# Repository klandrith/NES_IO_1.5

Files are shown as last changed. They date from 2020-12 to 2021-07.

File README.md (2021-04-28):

NES-I/O 1.5
===========

From original Borti's project: https://github.com/borti4938/NES_IGR_for_NESRGB/tree/master/NES-IO

an idea by Arcade-TV from circuit-board.de :) Thank you very much!!!

The board replaces the silver box in NES frontloader. On this PCB the following components are included:

- AC input jack
- AC to DC conversion
- MultiAV (SNES and GC(*) are supported) 
- PIC16F684 microcontroller to control the NESRGB color palette and reset the console using your controller :D

All components you need are stated on the silkscreen. An complete overview as well as an English installation guide is coming soon ;)

Grab the firmware for the PIC16F684 here: https://github.com/borti4938/NES_IGR_for_NESRGB/tree/master/fw/IGR_for_NESRGB/
- current version: use the 'normal version' and flash the nesrgb_igr_684_var_led.hex
- oldest PCB version (with three 10k resistors next to the 74*125): use the 'risky version' and flash nesrgb_igr_684_risky_var_led.hex

(*) 3d-printed Helder/Buffalowing connector on assemblergames (http://assemblergames.com/l/threads/f-s-nes-top-loader-snes-style-multi-a-v-socket.50494/) also fits  
    thanks for figuring out, splits (shmups forum)

-- The Rev 1.5 add the audio module, and there is now a NO CUT version where a miniDIN 9pin and a miniDIN 4pin replace the SNES/GC Multiout.
--
-- YOU'LL NEED TO REMOVE THE 3 RESISTORS ON THE RGB LINES OF THE NESRGB BOARD IF YOU ARE USING THE NOCUT BOARDS
--

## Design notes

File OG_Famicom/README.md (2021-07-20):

Famicom-I/O 1.5
===========

This is the Original Famicom folder.

The Classic SNES Multiout requires the following PCBs (gerber zipped files):
- Famicom_IO_SNES_REV1.5
- Audio_Blank
- Famicon_IO_Jack_Spacer

The NOCUT requires the following PCBs (gerber zipped files):
- Famicom_IO_NOCUT_REV1.5
- Audio_Blank
- Famicon_IO_Jack_Spacer

Installation Notes:
- For the NOCUT version, you need to remove the 75omhs resistors on the RGB lines of the NESRGB

- PDF installation guide link: https://github.com/TRP-Retromods/NES_IO_1.5/blob/master/OG_Famicom/Famicom_IO_Installation.pdf

Audio
- For default installation, you have 3 possibilies

1) No expansion: you simply take CPU pins 1&2 to A&B inputs of the NESRGB, then link O ouput to "Mono" of the Famicom I/O
2) Expansion only: you need to CUT the trace going to pin 45 of the Cart slot (as per Tim's installation guide). As Tim said: "connect the A and B inputs to the PPU, connect the cartridge output pin via a resistor to the mixing point (located next to jumper J5). The cartridge input pin needs to be disconnected from the existing mixer circuit on the motherboard. Replace it with a mid supply reference (maybe 4k7 to +5V, 4k7 to ground, bypassed with a 10u capacitor)"
3) Original mixing (TO BE TESTED) : quote "Alternatively, you can continue to use the original mixer circuit and just use the NESRGB audio circuit as a buffer. To do this connect the cartridge output through a 27k resistor to the A audio input on the NESRGB board. Leave the B audio input unconnected. This makes the audio circuit into unity gain buffer. You will also probably want to remove C30 as it will attenuate the high frequency signals too much in this configuration."

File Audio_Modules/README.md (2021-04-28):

NES-I/O 1.5
===========

This is the Audio Module folder.

You'll find audio that can replace the blank one on the NES I/O / Famicom I/O Rev 1.5

* Tianfeng audio - This will take directly from the CPU Pin 1/2 and expansion cart pin.

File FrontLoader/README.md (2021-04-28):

NES-I/O 1.5
===========

This is the FrontLoader folder.

The Classic SNES Multiout requires the following PCBs (gerber zipped files):
- NES_IO_US_REV1.5_SNES
- Audio_Blank

The NOCUT requires the following PCBs (gerber zipped files):
- NES_IO_US_REV1.5_NOCUT
- miniDIN4_spacer
- Audio_Blank

-- You need to send to fab the blank audio module PCB for all versions, and the miniDIN 4 spacer IN 1MM THICK for the NOCUT.
--
-- You'll need to cut some parts on the PCBs: they are currently designed to avoid extra costs on castelated vias.
--
-- They are around the RCA plugs and on the miniDIN4_spacer.
--

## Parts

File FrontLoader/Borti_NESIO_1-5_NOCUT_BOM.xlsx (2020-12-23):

Manufacturer Part Number | Manufacturer | Digi-Key Part Number | Customer Reference | Reference Designator | Packaging | Part Status | Quantity | Unit Price | Extended Price | Quantity Available | Mfg Std Lead Time | Description | RoHS Status | Lead Free Status | REACH Status
RCJ-012 | CUI Devices | CP-1401-ND | BORTI'S NES IO |  | Bulk | Active | 1 | 1.03 | $1.03 | 35 | 11 Weeks | CONN RCA JACK MONO 3.2MM R/A | RoHS Compliant | Lead free | Not Available
RCJ-014 | CUI Devices | CP-1403-ND | BORTI'S NES IO |  | Bulk | Active | 1 | 1.03 | $1.03 | 2923 | 11 Weeks | CONN RCA JACK MONO 3.2MM R/A | RoHS Compliant | Lead free | Not Available
EEE-1VA100WR | Panasonic Electronic Components | PCE3948CT-ND | BORTI'S NES IO | C4 | Cut Tape (CT) | Active | 1 | 0.42 | $0.42 | 33434 | 26 Weeks | CAP ALUM 10UF 20% 35V SMD | RoHS Compliant | Lead free | Not Available
UWJ0J101MCL1GB | Nichicon | 493-9777-1-ND | BORTI'S NES IO | C5 | Cut Tape (CT) | Active | 1 | 0.48 | $0.48 | 3177 | 20 Weeks | CAP ALUM 100UF 20% 6.3V SMD | ROHS3 Compliant | Lead free | REACH Unaffected
OKI-78SR-5/1.5-W36-C | Murata Power Solutions Inc. | 811-2196-5-ND | BORTI'S NES IO |  | Tray | Active | 1 | 6.08 | $6.08 | 1295 | 14 Weeks | DC DC CONVERTER 5V 8W | RoHS Compliant | Lead free | REACH Unaffected
74LVX125MX | ON Semiconductor | 74LVX125MXCT-ND | BORTI'S NES IO |  | Cut Tape (CT) | Active | 1 | 0.83 | $0.83 | 1578 | 8 Weeks | IC BUF NON-INVERT 3.6V 14SOIC | ROHS3 Compliant | Lead free | REACH Unaffected
CL21B103KAANNNC | Samsung Electro-Mechanics | 1276-2434-1-ND | BORTI'S NES IO | C1, C3, C6 | Cut Tape (CT) | Active | 3 | 0.14 | $0.42 | 118307 | 22 Weeks | CAP CER 10000PF 25V X7R 0805 | ROHS3 Compliant | Lead free | REACH Unaffected
56000001009 | Littelfuse Inc. | WK6235-ND | BORTI'S NES IO | F1 | Bulk | Active | 1 | 1.19 | $1.19 | 21271 | 12 Weeks | FUSE HOLDER RADIAL 250V 6.3A PCB | ROHS3 Compliant | Lead free | Not Available
MRT 1.25-BULK | Bel Fuse Inc. | 507-1112-ND | BORTI'S NES IO | F1 | Bulk | Active | 1 | 0.48 | $0.48 | 914 | 18 Weeks | FUSE BRD MNT 1.25A 250VAC RADIAL | ROHS3 Compliant | Lead free | REACH Unaffected
PIC16F684-I/SL | Microchip Technology | PIC16F684-I/SL-ND | BORTI'S NES IO |  | Tube | Active | 1 | 2.06 | $2.06 | 3297 | 19 Weeks | IC MCU 8BIT 3.5KB FLASH 14SOIC | ROHS3 Compliant | Lead free | REACH Unaffected
1N5059GP-E3/54 | Vishay Semiconductor Diodes Division | 1N5059GP-E3/54GICT-ND | BORTI'S NES IO | D1, D2, D3, D4 | Cut Tape (CT) | Active | 4 | 0.52 | $2.08 | 19206 | 18 Weeks | DIODE GEN PURP 200V 1A DO204AC | ROHS3 Compliant | Lead free | REACH Unaffected
25PK2200MEFC12.5X20 | Rubycon | 1189-1731-ND | BORTI'S NES IO | C2 | Bulk | Active | 1 | 1.19 | $1.19 | 16646 | 17 Weeks | CAP ALUM 2200UF 20% 25V RADIAL | ROHS3 Compliant | Lead free | REACH Unaffected
CL21B104MBCNNNC | Samsung Electro-Mechanics | 1276-2450-1-ND | BORTI'S NES IO | C7, C9 | Cut Tape (CT) | Obsolete | 2 | 0.14 | $0.28 | 2069590 | 22 Weeks | CAP CER 0.1UF 50V X7R 0805 | ROHS3 Compliant | Lead free | REACH Unaffected
RMCF0805FT1K00 | Stackpole Electronics Inc | RMCF0805FT1K00CT-ND | BORTI'S NES IO | R6, R7 | Cut Tape (CT) | Active | 2 | 0.15 | $0.30 | 370416 | 18 Weeks | RES 1K OHM 1% 1/8W 0805 | ROHS3 Compliant | Lead free | REACH Unaffected
RMCF0805FT180R | Stackpole Electronics Inc | RMCF0805FT180RCT-ND | BORTI'S NES IO | R1, R2 | Cut Tape (CT) | Active | 2 | 0.15 | $0.30 | 37701 | 18 Weeks | RES 180 OHM 1% 1/8W 0805 | ROHS3 Compliant | Lead free | REACH Unaffected
PJ-002A | CUI Devices | CP-002A-ND | BORTI'S NES IO |  | Bulk | Active | 1 | 0.85 | $0.85 | 39799 | 11 Weeks | CONN PWR JACK 2X5.5MM SOLDER | RoHS Compliant | Lead free | Not Available
RMCF0805FT10K0 | Stackpole Electronics Inc | RMCF0805FT10K0CT-ND | BORTI'S NES IO | J2 | Cut Tape (CT) | Active | 1 | 0.15 | $0.15 | 4314324 | 18 Weeks | RES 10K OHM 1% 1/8W 0805 | ROHS3 Compliant | Lead free | REACH Unaffected
MDJ-009-FS | Adam Tech | 2057-MDJ-009-FS-ND |  |  | Tray | Active | 1 | 1.73 | $1.73 | 758 | 9 Weeks | CONN JACK FMALE MINI DIN 9P SLDR | ROHS3 Compliant | Lead free | REACH Unaffected
KMDGX-4S-BS | Kycon, Inc. | 2092-KMDGX-4S-BS-ND |  |  | Tray | Active | 1 | 1.8 | $1.80 | 6594 | 20 Weeks | CONN RCPT FMALE MINI DIN 4P SLDR | RoHS Compliant | Lead free | Not Available
310-87-108-41-001101 | Preci-Dip | 1212-1097-ND |  |  | Bulk | Active | 1 | 0.78 | $0.78 | 5099 | 10 Weeks | CONN SOCKET 8POS 0.1 GOLD PCB | ROHS3 Compliant | Lead free | REACH Unaffected
TS-108-T-A | Samtec Inc. | SAM1112-08-ND |  |  | Bulk | Active | 1 | 1.49 | $1.49 | 1752 | 2 Weeks | CONN HEADER VERT 8POS 2.54MM | ROHS3 Compliant | Lead free | REACH Unaffected

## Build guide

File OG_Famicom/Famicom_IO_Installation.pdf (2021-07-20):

FAMICOM I/O Installation Guide | 1

# Installation of the FAMICOM I/O (Classic and No Cut)

# FIRST YOU NEED TO READ THE ORIGINAL INSTALLATION OF THE NESRGB FROM TIM WORTHINGTON AND NES I/O FROM BORTI (yes the Front Loader one) TO UNDERSTAND WHAT YOU ARE DOING Links:

# https://etim.net.au/nesrgb/installation-famicom/ https://github.com/borti4938/NES_IGR_for_NESRGB/blob/master/NES-IO/NESIO_Installation.pdf

# THIS IS EXPERIMENTAL, I CANNOT BE HOLD RESPONSIBLE FOR ANY DAMAGE CAUSED TO YOUR CONSOLE

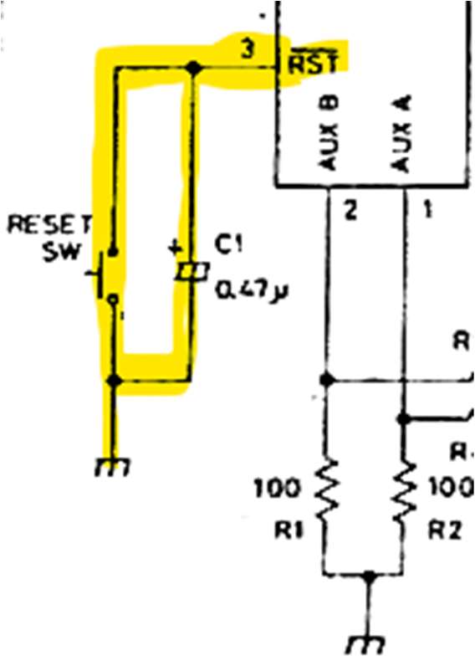
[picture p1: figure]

FAMICOM I/O Installation Guide | 2

### 1) RGB/Video/Palette

Those are identical as a classic NESRGB+NES I/O installation. Check respective installation guides of each.

### 2) RESET

a) Preparations
The reset is different in the OG Famicom from the NES Front Loader: there’s no CIC and you cannot intercept the reset signal which is going straight to the CPU pin:

You need to intercept the signal and re-route the Famicom I/O BEFORE it goes the CPU. You can cut the trace close the reset switch:

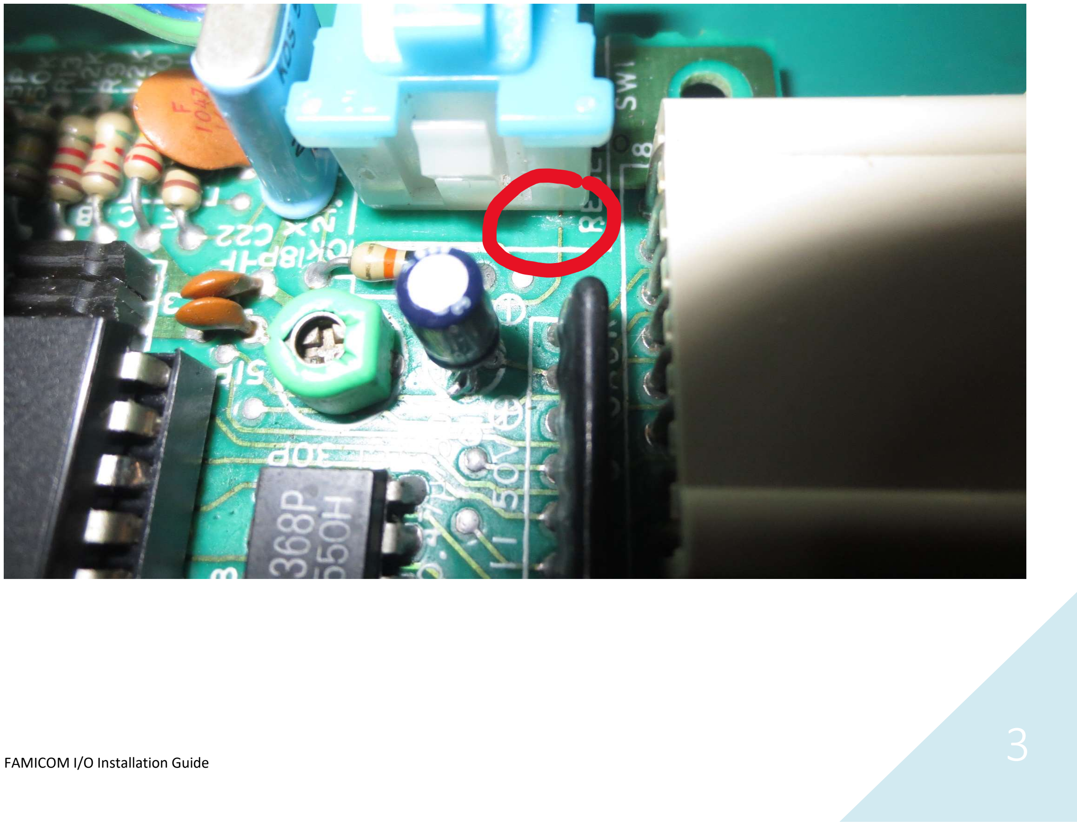
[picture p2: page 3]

FAMICOM I/O Installation Guide

3

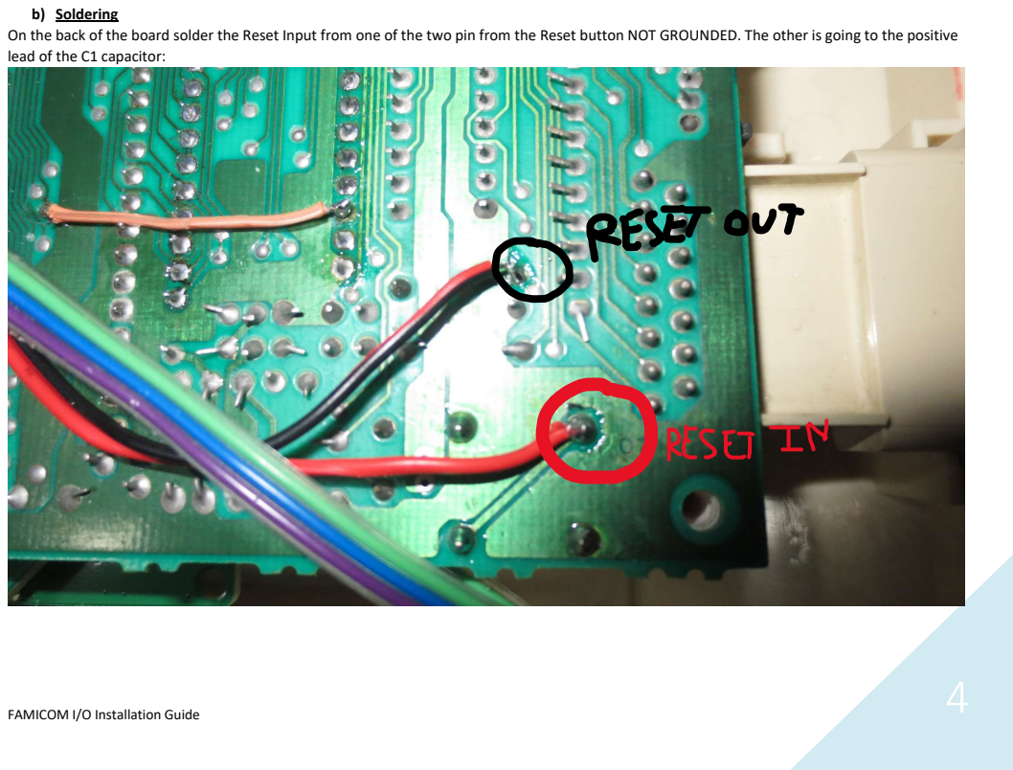
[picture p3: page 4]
FAMICOM I/O Installation Guide

b) Soldering
On the back of the board solder the Reset Input from one of the two pin from the Reset button NOT GROUNDED. The other is going to the positive
lead of the C1 capacitor:

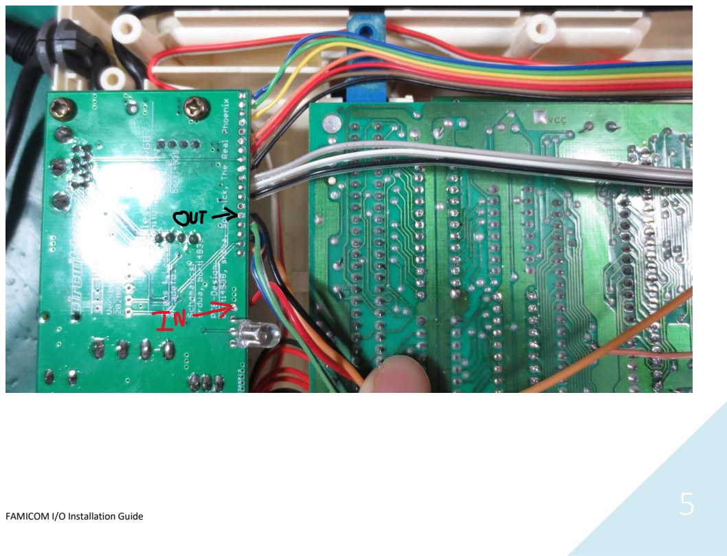
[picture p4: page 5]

FAMICOM I/O Installation Guide

### 3) PULSE, LATCH and DATA

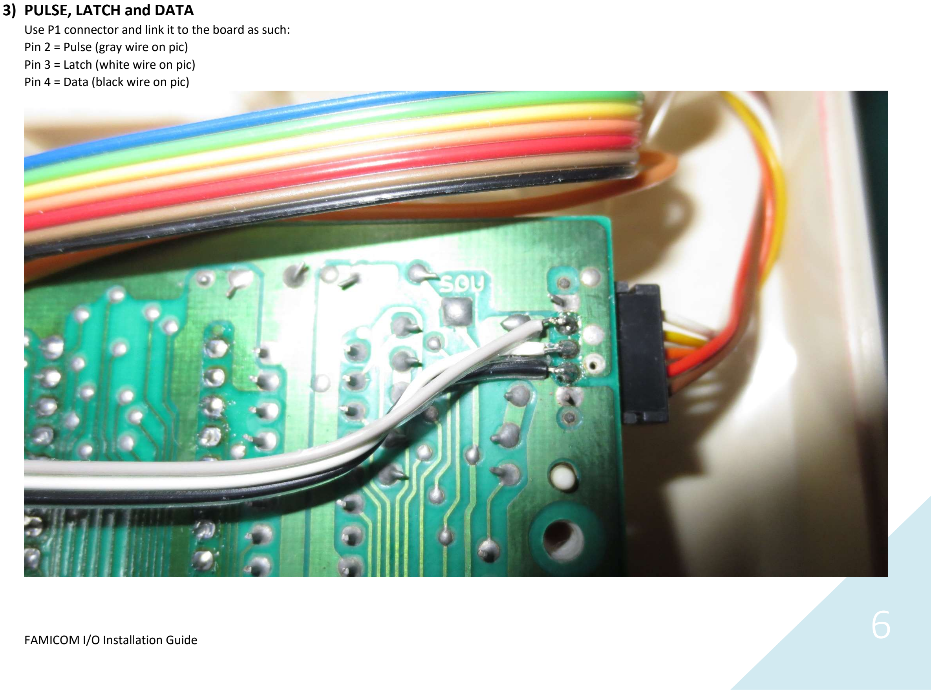
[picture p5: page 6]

FAMICOM I/O Installation Guide | 6

Use P1 connector and link it to the board as such: Pin 2 = Pulse (gray wire on pic)
Pin 3 = Latch (white wire on pic)
Pin 4 = Data (black wire on pic)

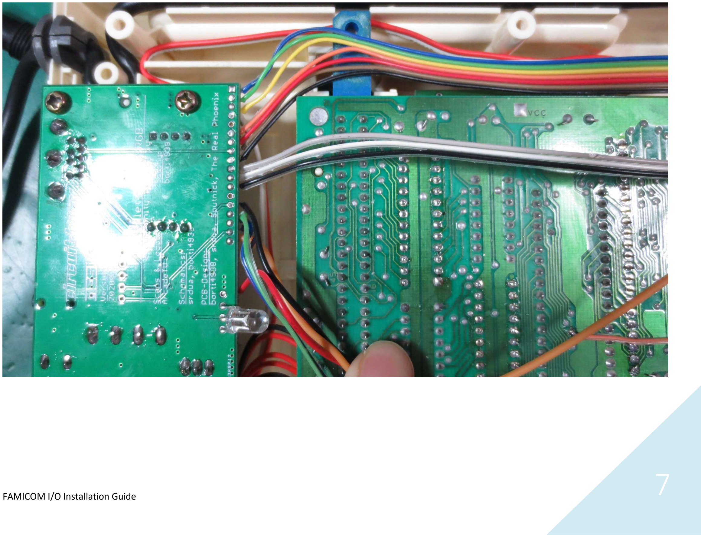
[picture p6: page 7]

FAMICOM I/O Installation Guide

7

### 4) Power

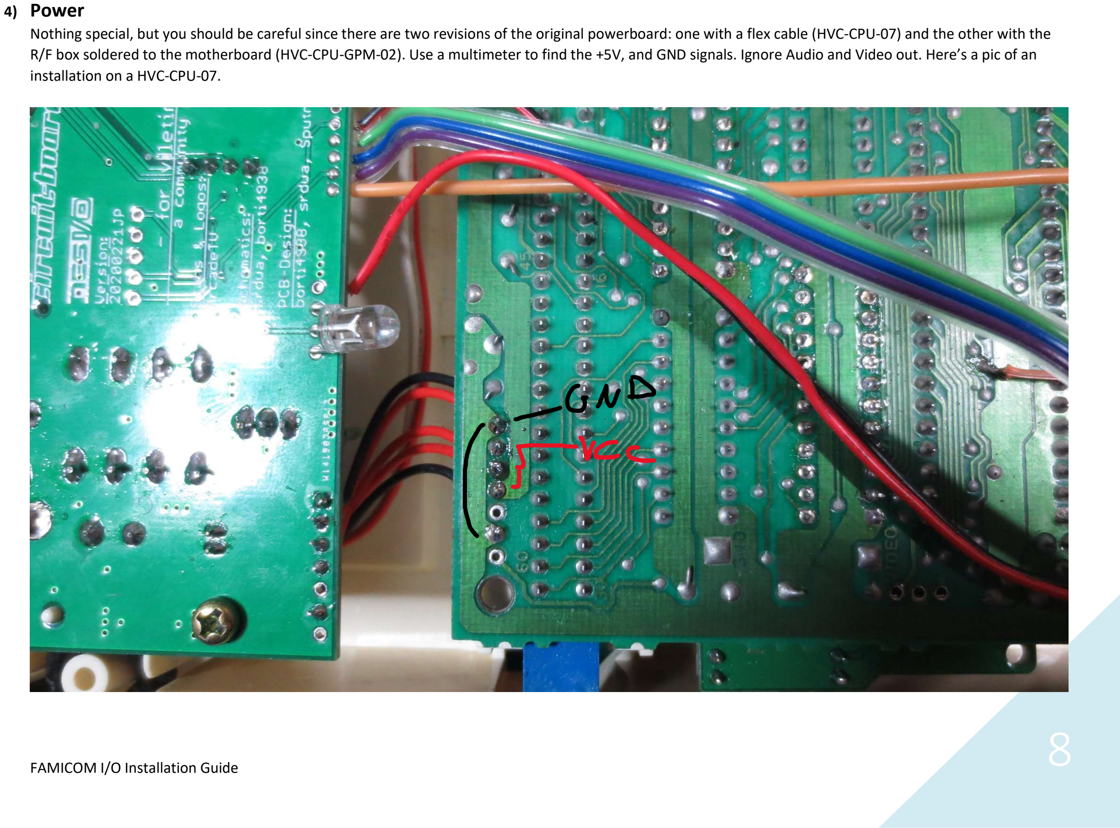
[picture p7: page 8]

FAMICOM I/O Installation Guide | 8

Nothing special, but you should be careful since there are two revisions of the original powerboard: one with a flex cable (HVC-CPU-07) and the other with the R/F box soldered to the motherboard (HVC-CPU-GPM-02). Use a multimeter to find the +5V, and GND signals. Ignore Audio and Video out. Here’s a pic of an installation on a HVC-CPU-07.

### 5) Audio

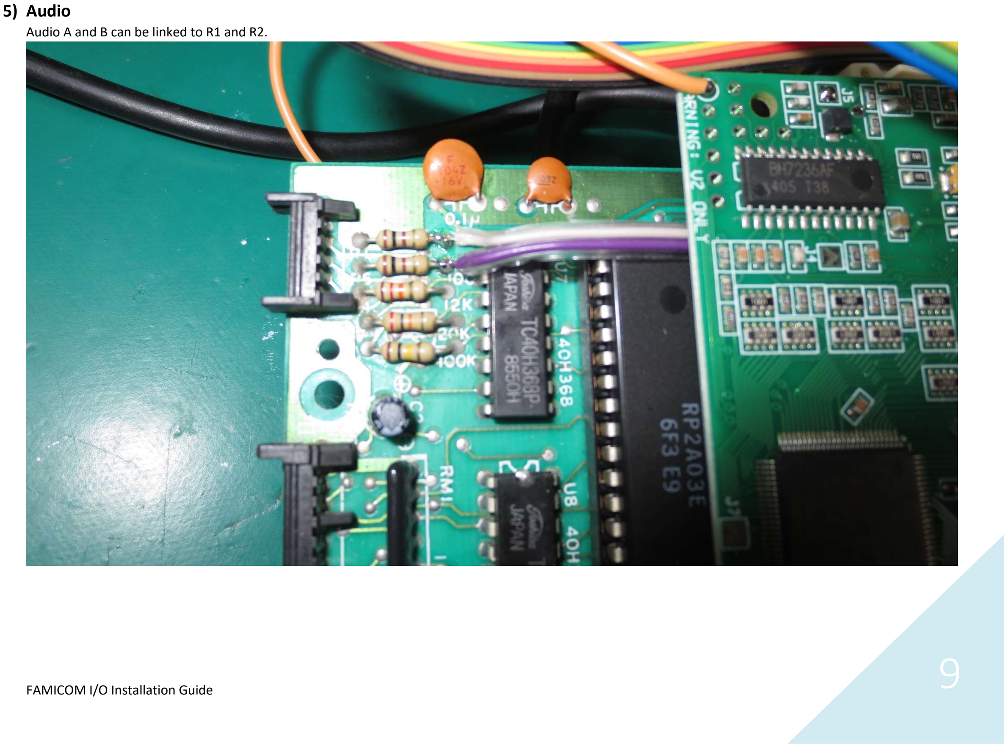
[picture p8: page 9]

FAMICOM I/O Installation Guide | 9

Audio A and B can be linked to R1 and R2.

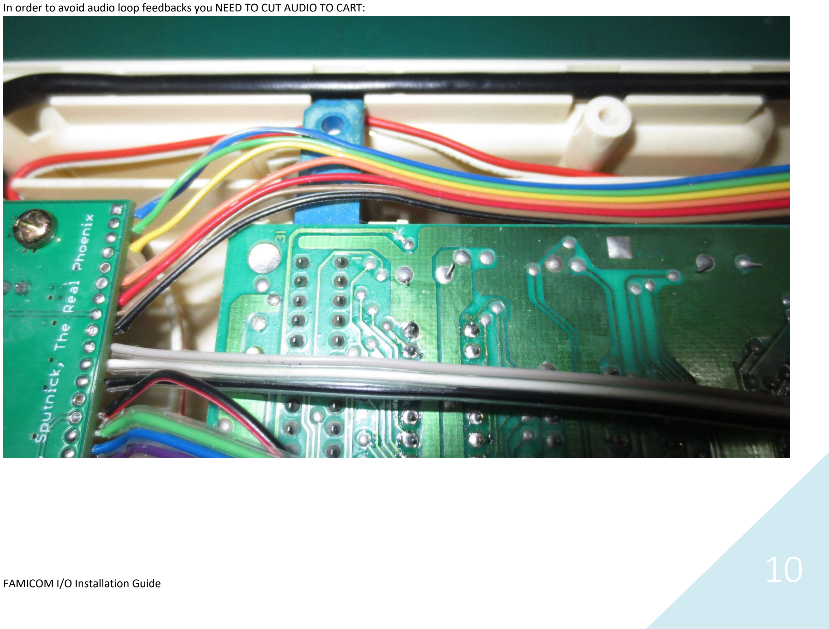
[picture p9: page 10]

FAMICOM I/O Installation Guide | 10

In order to avoid audio loop feedbacks you NEED TO CUT AUDIO TO CART:

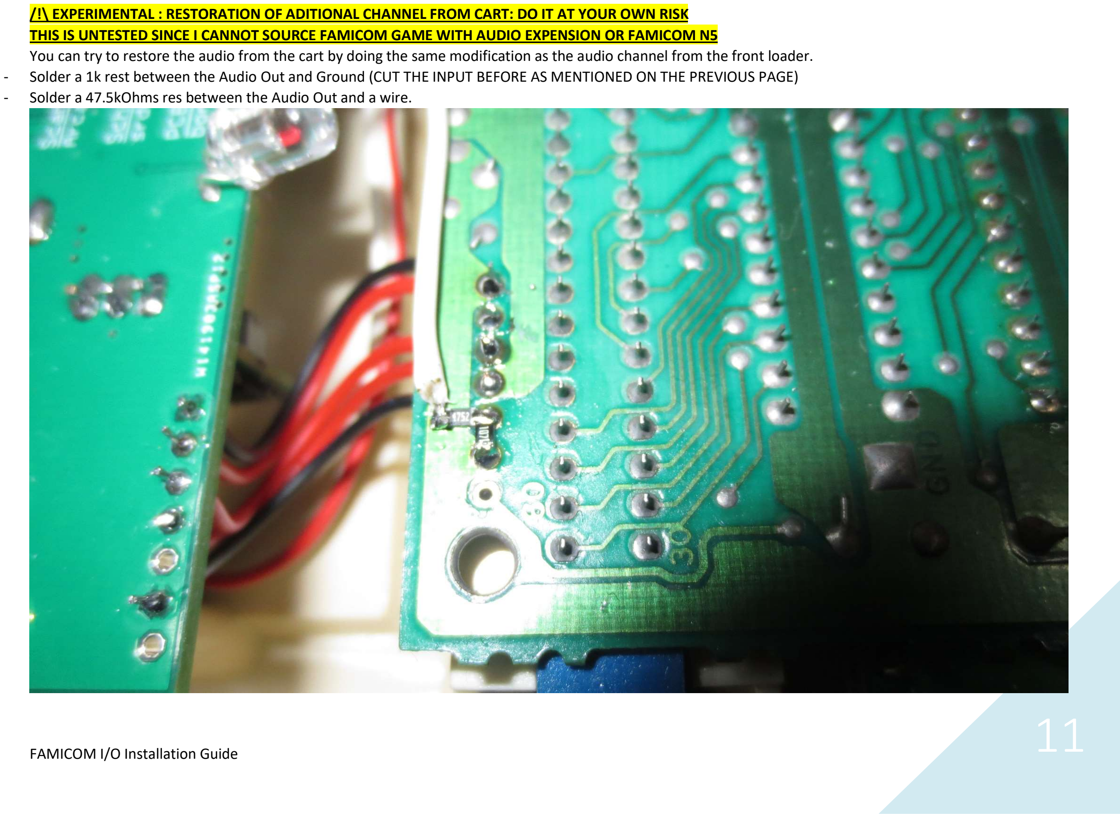
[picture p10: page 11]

FAMICOM I/O Installation Guide | 11

/!\ EXPERIMENTAL : RESTORATION OF ADITIONAL CHANNEL FROM CART: DO IT AT YOUR OWN RISK
THIS IS UNTESTED SINCE I CANNOT SOURCE FAMICOM GAME WITH AUDIO EXPENSION OR FAMICOM N5
You can try to restore the audio from the cart by doing the same modification as the audio channel from the front loader.
- Solder a 1k rest between the Audio Out and Ground (CUT THE INPUT BEFORE AS MENTIONED ON THE PREVIOUS PAGE)
- Solder a 47.5kOhms res between the Audio Out and a wire.

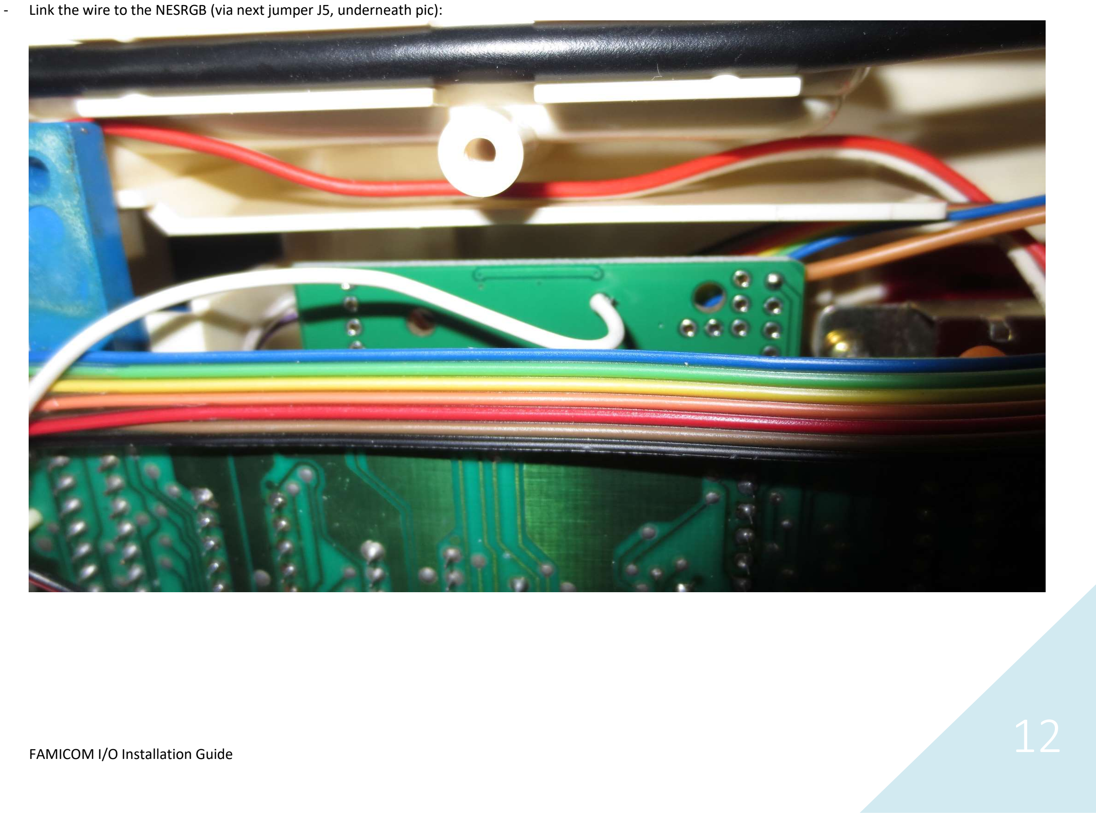
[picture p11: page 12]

FAMICOM I/O Installation Guide | 12
- Link the wire to the NESRGB (via next jumper J5, underneath pic):

### 6) Fixing the Famicom I/O

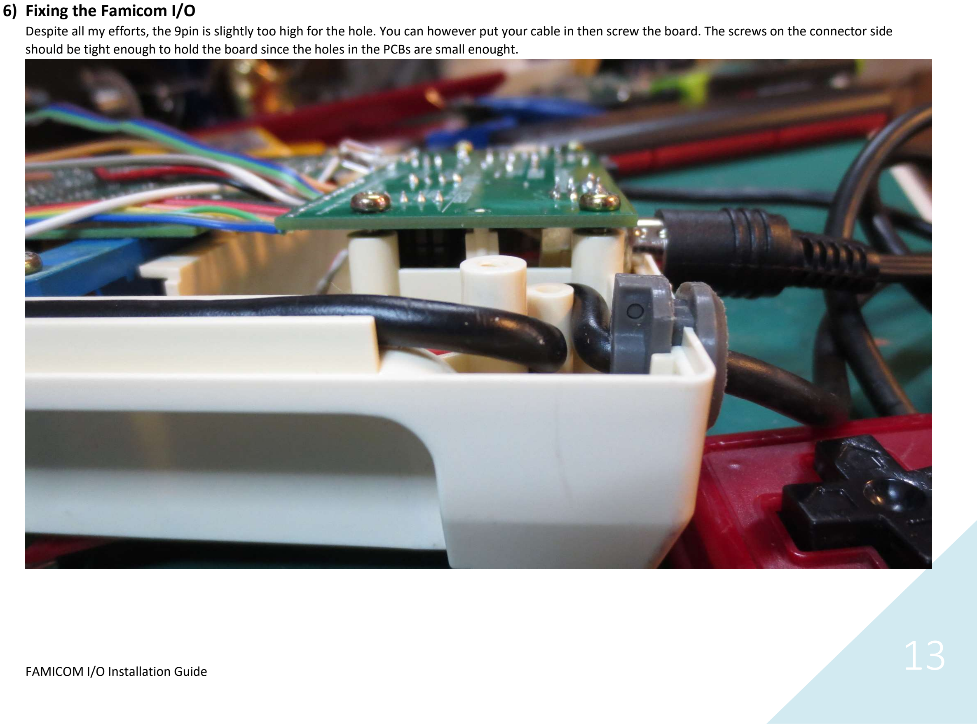
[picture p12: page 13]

FAMICOM I/O Installation Guide | 13

Despite all my efforts, the 9pin is slightly too high for the hole. You can however put your cable in then screw the board. The screws on the connector side should be tight enough to hold the board since the holes in the PCBs are small enought.

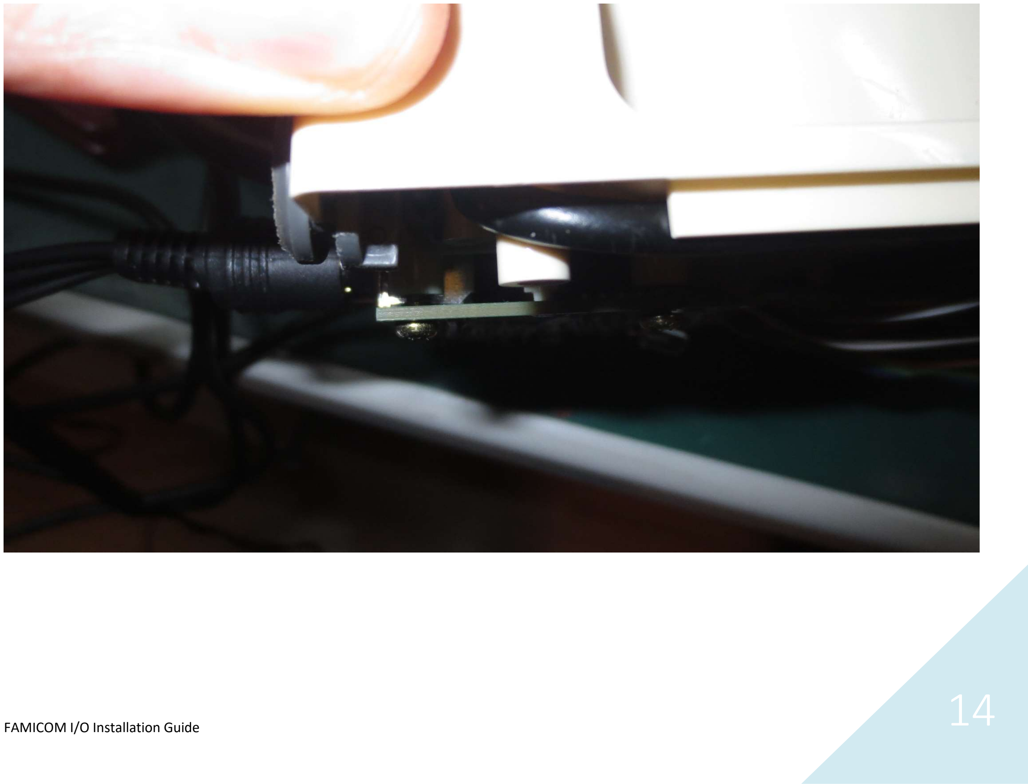
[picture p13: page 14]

FAMICOM I/O Installation Guide | 14

7) Pics of prototype installation (ignore the tiny orange wire in the CPU which is a destroyed vias restoration:

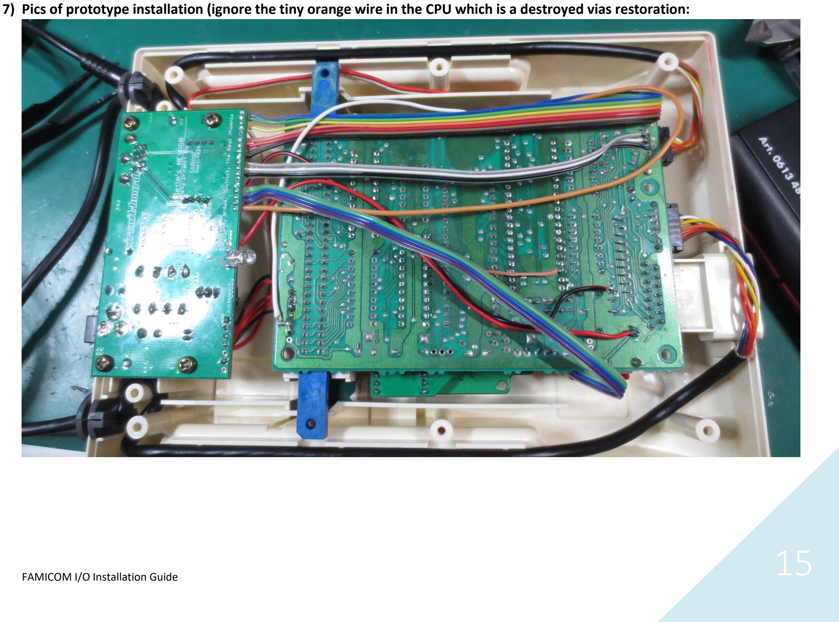
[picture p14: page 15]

FAMICOM I/O Installation Guide | 15

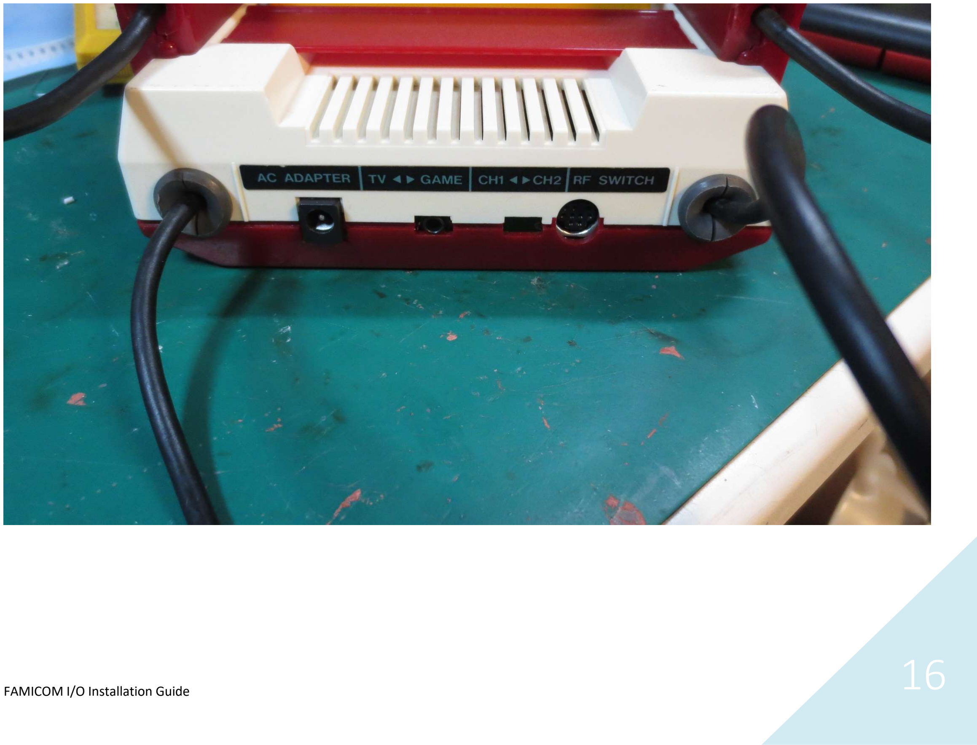
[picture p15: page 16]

FAMICOM I/O Installation Guide | 16

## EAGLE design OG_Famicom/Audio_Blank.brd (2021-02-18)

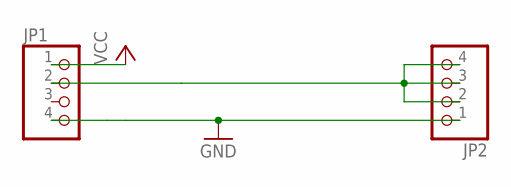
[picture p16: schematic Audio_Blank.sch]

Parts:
JP1, JP2: PINHD-1X04_2.54-S; 1X04-S

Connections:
GND: JP1.4, JP2.1
unnamed: JP1.2, JP2.2, JP2.3, JP2.4
VCC: JP1.1

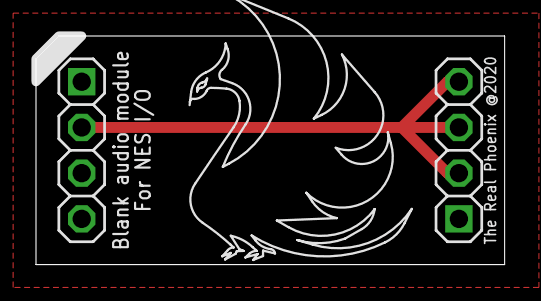
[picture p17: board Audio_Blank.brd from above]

Board: 2 copper layers, 26.0 x 12.7 mm, 3 parts (0 on the bottom side), 2 nets.

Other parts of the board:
U$1: LOGO

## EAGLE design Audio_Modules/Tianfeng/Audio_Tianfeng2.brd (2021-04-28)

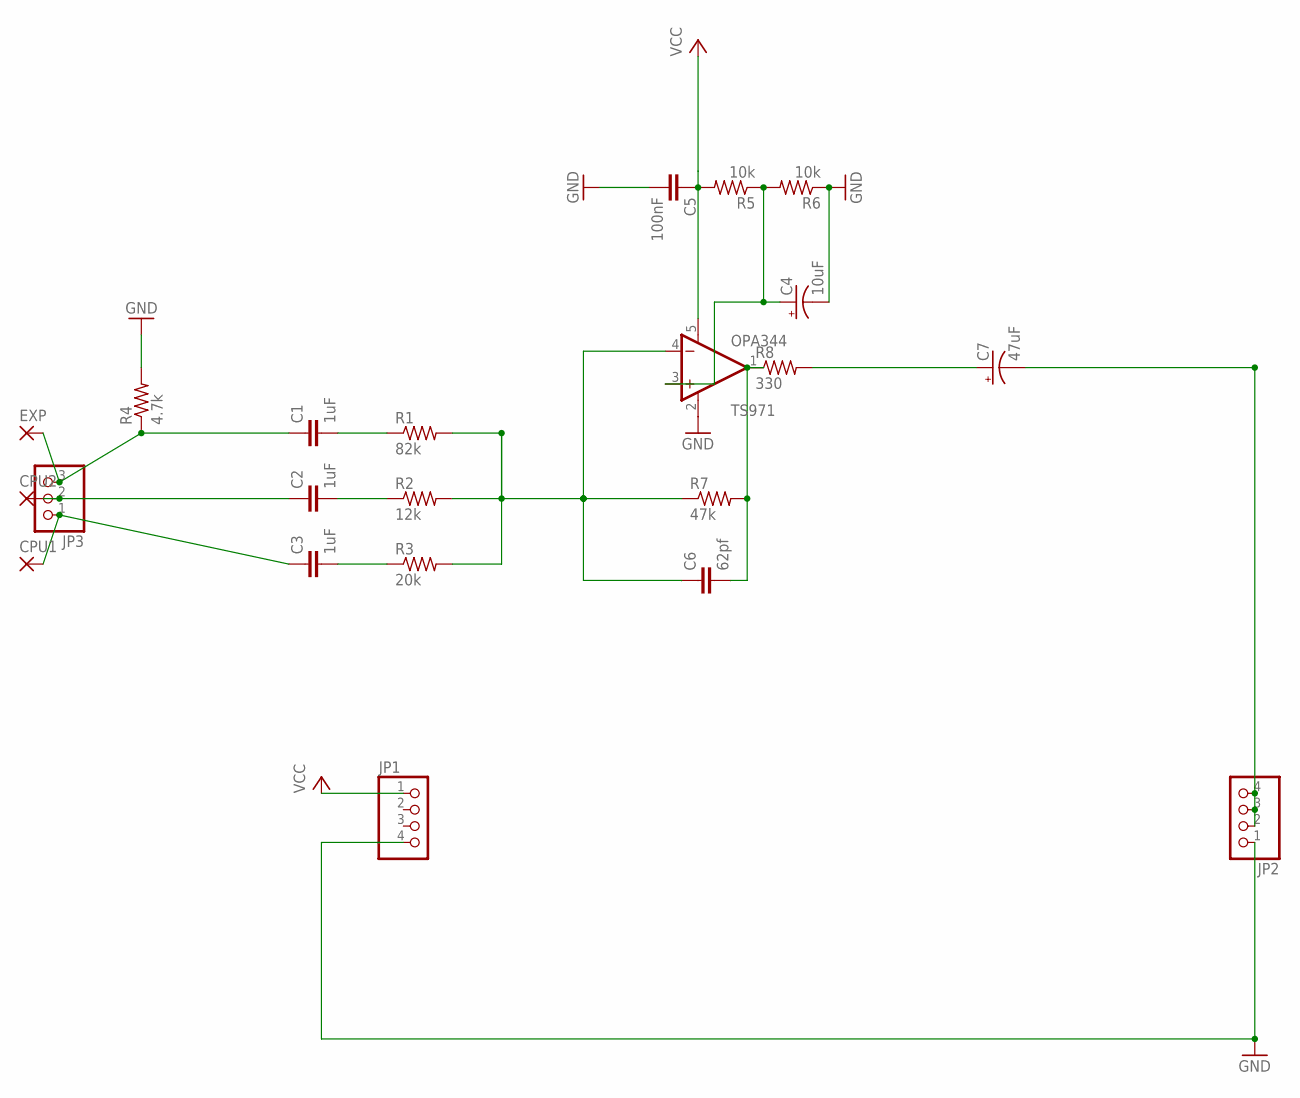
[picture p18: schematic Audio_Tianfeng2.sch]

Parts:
C1, C2, C3: 1uF; C0603K
C4: 10uF; 153CLV-0405
C5: 100nF; C0603K
C6: 62pf; C0603K
C7: 47uF; 153CLV-0405
CPU1, CPU2: SMD2; SMD1,27-2,54
EXP: SMD2; SMD1,27-2,54
JP1, JP2: PINHD-1X04_2.54-S; 1X04-S
JP3: PINHD-1X03_2.54-S; 1X03-S
R1: 82k; R0603
R2: 12k; R0603
R3: 20k; R0603
R4: 4.7k; R0603
R5, R6: 10k; R0603
R7: 47k; R0603
R8: 330; R0603
TS971: OPA344; SOT23-5

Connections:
GND: C4.-, C5.2, JP1.4, JP2.1, R4.2, R6.1, TS971.2 (V-)
unnamed: C1.2, R1.1
unnamed: C2.2, R2.1
unnamed: C4.+, R5.1, R6.2, TS971.3 (+IN)
unnamed: C7.-, JP2.2, JP2.3, JP2.4
unnamed: C3.2, R3.1
unnamed: C6.1, R1.2, R2.2, R3.2, R7.1, TS971.4 (-IN)
unnamed: C1.1, EXP.1, JP3.3, R4.1
unnamed: C2.1, CPU2.1, JP3.2
unnamed: C3.1, CPU1.1, JP3.1
unnamed: C6.2, R7.2, R8.1, TS971.1 (OUT)
unnamed: C7.+, R8.2
VCC: C5.1, JP1.1, R5.2, TS971.5 (V+)

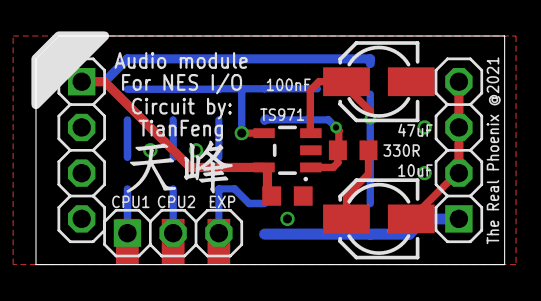
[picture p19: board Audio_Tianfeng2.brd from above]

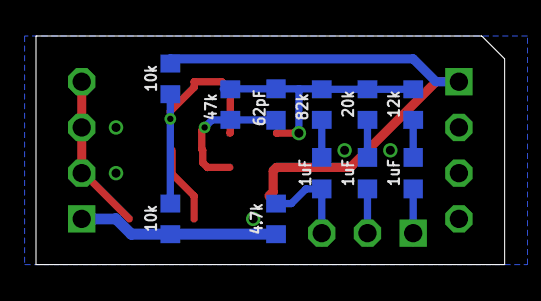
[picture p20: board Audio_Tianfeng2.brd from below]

Board: 2 copper layers, 26.0 x 12.7 mm, 22 parts (11 on the bottom side), 13 nets.

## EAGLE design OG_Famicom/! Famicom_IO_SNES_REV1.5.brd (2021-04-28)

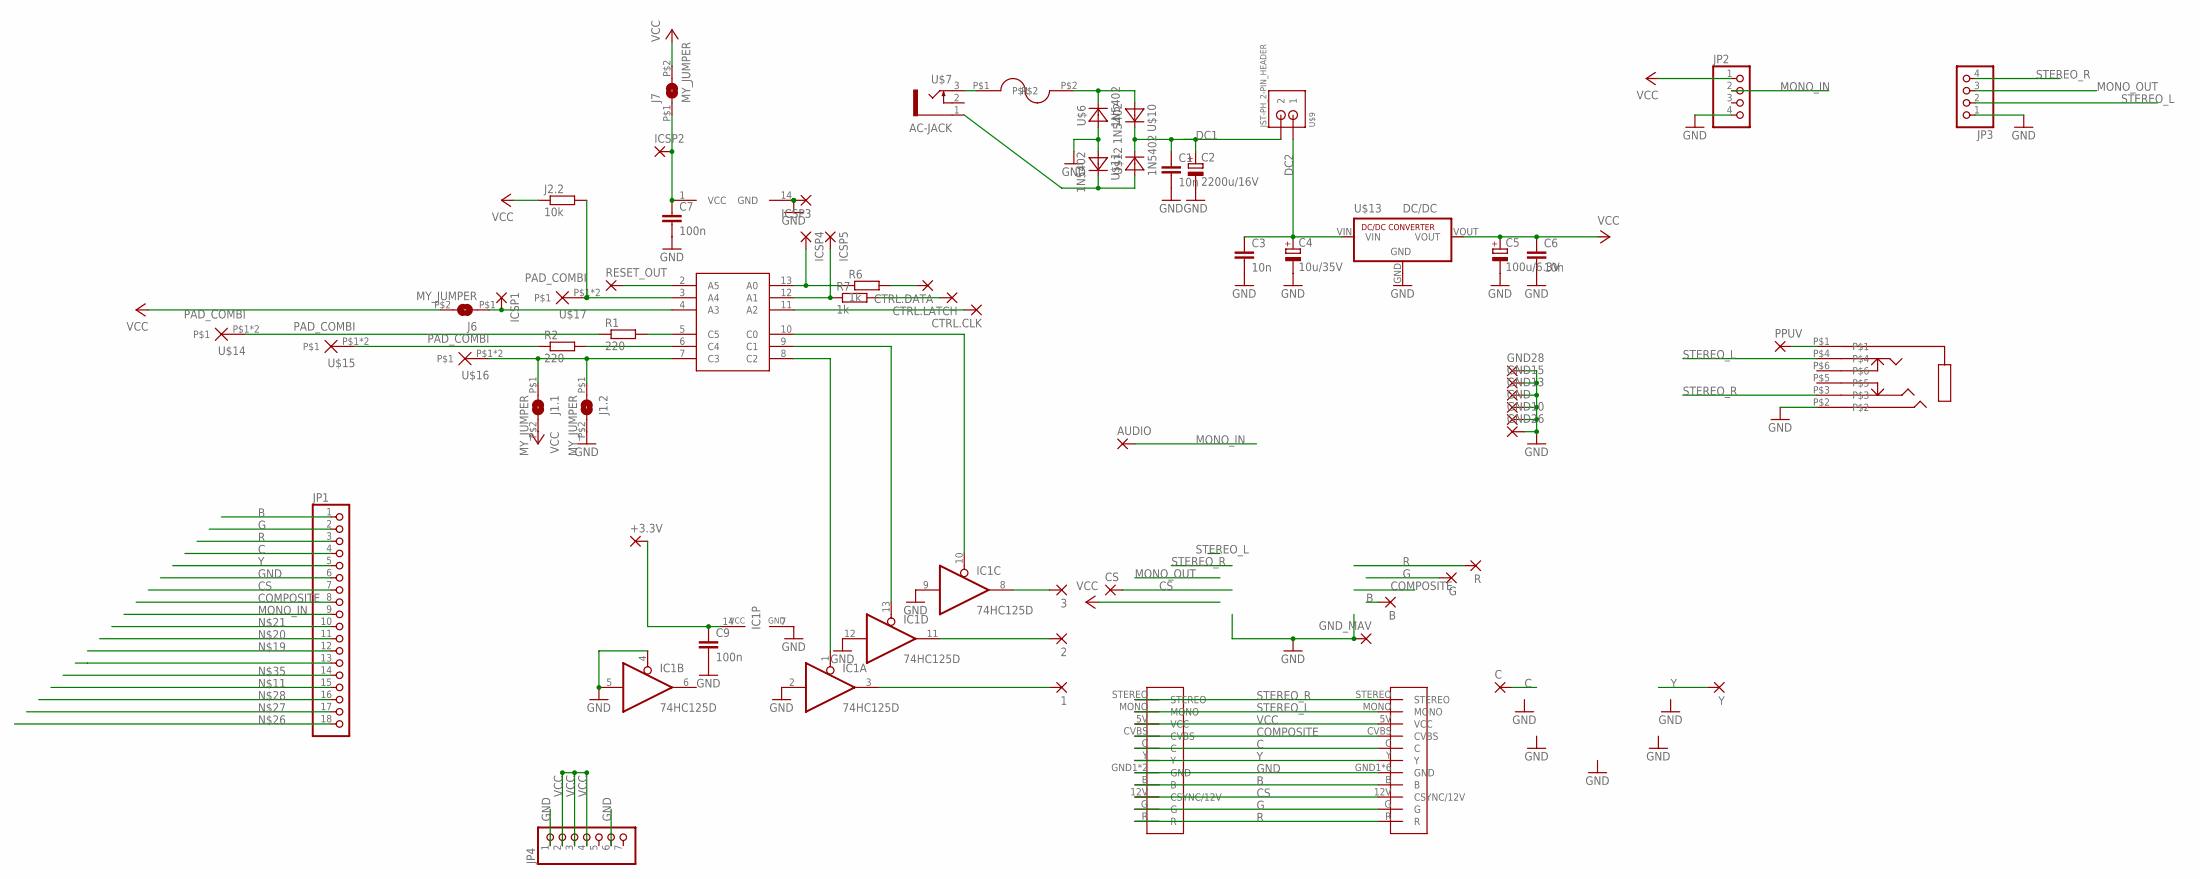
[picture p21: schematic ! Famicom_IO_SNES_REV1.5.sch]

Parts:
1, 2, 3: SMD2; SMD1,27-2,54
+3.3V: SMD2; SMD1,27-2,54
AUDIO: SMD2; SMD1,27-2,54
B: SMD2; SMD1,27-2,54
C: SMD2; SMD1,27-2,54
C1, C3, C6: 10n; Z0805
C2: 2200u/16V; E5-13
C4: 10u/35V; PANASONIC_B
C5: 100u/6.3V; PANASONIC_D
C7, C9: 100n; Z0805
CS: SMD2; SMD1,27-2,54
CTRL.CLK, CTRL.DATA, CTRL.LATCH: SMD2; SMD1,27-2,54
G: SMD2; SMD1,27-2,54
GND, GND10, GND13, GND15, GND26, GND28: SMD5; SMD2,54-5,08
GND_MAV: SMD2; SMD1,27-2,54
IC1: 74HC125D; SO14
ICSP1, ICSP2, ICSP3, ICSP4, ICSP5: 1,6/0,8
J1.1, J1.2, J6, J7: MY_JUMPER; MYJUMP
J2.2: 10k; Z0805
JP1: PINHD-1X18_2.00; 1X18M
JP2, JP3: PINHD-1X04_2.54-S; 1X04-S
JP4: PINHD-1X07_2.54-S; 1X07-S
PPUV: SMD2; SMD1,27-2,54
R: SMD2; SMD1,27-2,54
R1, R2: 220; Z0805
R6, R7: 1k; Z0805
RESET_OUT: SMD2; SMD1,27-2,54
U$2: FUSEHOLDER
U$5: PIC16F630_SIMPLE; PIC16F630
U$6, U$10, U$11, U$12: 1N5402; DO201
U$7: AC-JACK
U$8: PJ-342D; PJ-342
U$9: JST-PH_2-PIN_HEADER; JST_B2B-PH_HEADER
U$13: DC/DC; RECOM
U$14, U$15, U$16, U$17: PAD_COMBI
U$19: GC-MULTIAV
U$20: SNES-MULTIAV2
Y: SMD2; SMD1,27-2,54

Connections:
AC1A: U$2.P$1, U$7.3
AC1B: U$2.P$2, U$6.C, U$10.A
AC2: U$7.1 (5), U$11.C, U$12.A
B: B.1, JP1.1, U$19.B, U$20.B
C: C.1, JP1.4, U$19.C, U$20.C
COMPOSITE: JP1.8, PPUV.1, U$8.P$1, U$19.CVBS, U$20.CVBS
CS: CS.1, JP1.7, U$19.12V (CSYNC/12V), U$20.12V (CSYNC/12V)
DC1: C1.1, C2.+, U$9.P2 (2), U$10.C, U$12.C
DC2: C3.1, C4.+, U$9.P1 (1), U$13.VIN
G: G.1, JP1.2, U$19.G, U$20.G
GND: C1.2, C2.-, C3.2, C4.-, C5.-, C6.2, C7.2, C9.2, GND.1, GND10.1, GND13.1, GND15.1, GND26.1, GND28.1, GND_MAV.1, IC1.2 (I), IC1.4 (OE), IC1.5 (I), IC1.7 (GND), IC1.9 (I), IC1.12 (I), ICSP3.1, J1.2.P$2 (2), JP1.6, JP2.4, JP3.1, JP4.1, JP4.6, U$5.14 (GND), U$6.A, U$8.P$2, U$11.A, U$13.GND, U$19.GND1 (GND), U$19.GND2 (GND), U$19.GND3 (GND), U$19.GND4 (GND), U$19.GND5 (GND), U$19.GND6 (GND), U$20.GND1 (GND), U$20.GND2 (GND)
MONO_IN: AUDIO.1, JP1.9, JP2.2
MONO_OUT: JP3.3
unnamed: 3.1, IC1.8 (O), JP1.15
unnamed: J2.2.2, U$5.3 (A4), U$17.P$1, U$17.P$2
unnamed: R1.2, U$5.5 (C5)
unnamed: R2.2, U$5.6 (C4)
unnamed: R1.1, U$14.P$1, U$14.P$2
unnamed: R2.1, U$15.P$1, U$15.P$2
unnamed: J1.1.P$1 (1), J1.2.P$1 (1), U$5.7 (C3), U$16.P$1, U$16.P$2
unnamed: CTRL.DATA.1, JP1.12, R6.2
unnamed: CTRL.LATCH.1, JP1.11, R7.2
unnamed: CTRL.CLK.1, JP1.10, U$5.11 (A2)
unnamed: IC1.10 (OE), U$5.10 (C0)
unnamed: IC1.13 (OE), U$5.9 (C1)
unnamed: IC1.1 (OE), U$5.8 (C2)
unnamed: +3.3V.1, C9.1, IC1.14 (VCC), JP1.18
unnamed: 1.1, IC1.3 (O), JP1.17
unnamed: 2.1, IC1.11 (O), JP1.16
unnamed: C7.1, ICSP2.1, J7.P$1 (1), U$5.1 (VCC)
unnamed: ICSP1.1, J6.P$1 (1), U$5.4 (A3)
unnamed: ICSP4.1, R6.1, U$5.13 (A0)
unnamed: ICSP5.1, R7.1, U$5.12 (A1)
unnamed: JP1.14, RESET_OUT.1, U$5.2 (A5)
R: JP1.3, R.1, U$19.R, U$20.R
STEREO_L: JP3.2, U$8.P$4, U$19.MONO, U$20.MONO
STEREO_R: JP3.4, U$8.P$3, U$19.STEREO, U$20.STEREO
VCC: C5.+, C6.1, J1.1.P$2 (2), J2.2.1, J6.P$2 (2), J7.P$2 (2), JP2.1, JP4.2, JP4.3, JP4.4, U$13.VOUT, U$19.5V (VCC), U$20.5V (VCC)
Y: JP1.5, U$19.Y, U$20.Y, Y.1

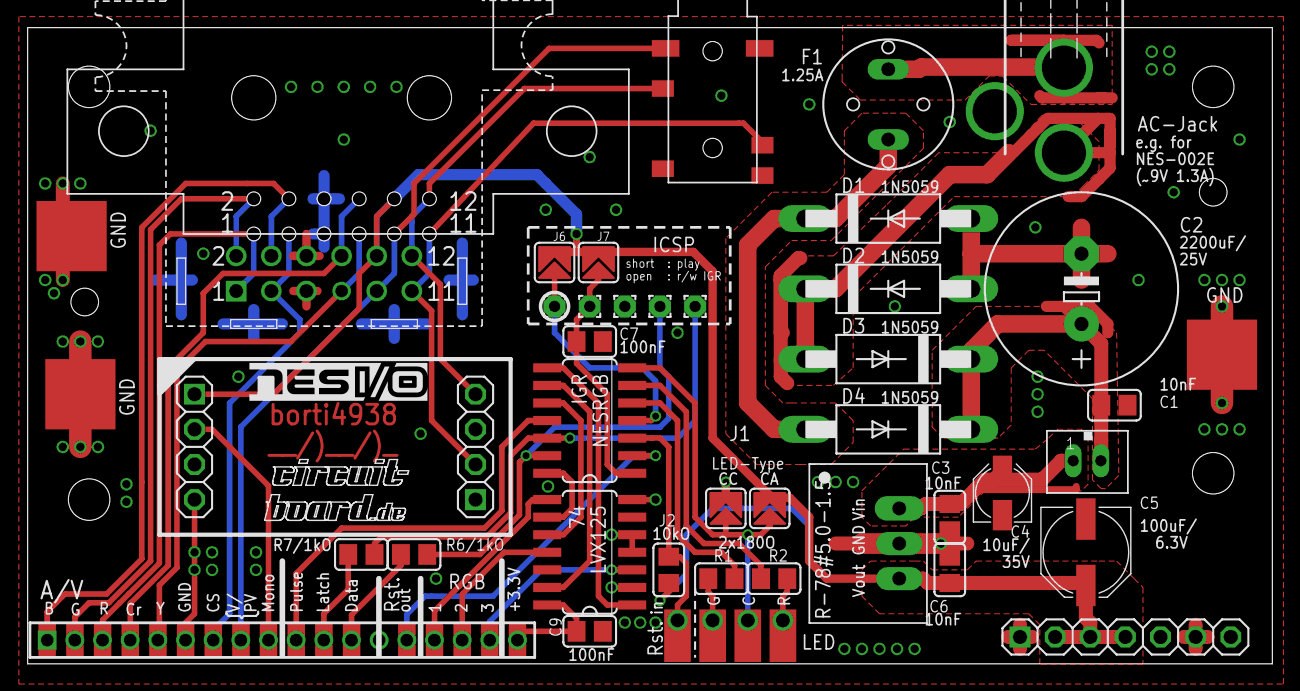
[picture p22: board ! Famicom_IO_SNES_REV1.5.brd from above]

Board: 2 copper layers, 90.0 x 46.0 mm, 68 parts (1 on the bottom side), 38 nets.

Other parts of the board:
U$3, U$4: NESIO-LOGO

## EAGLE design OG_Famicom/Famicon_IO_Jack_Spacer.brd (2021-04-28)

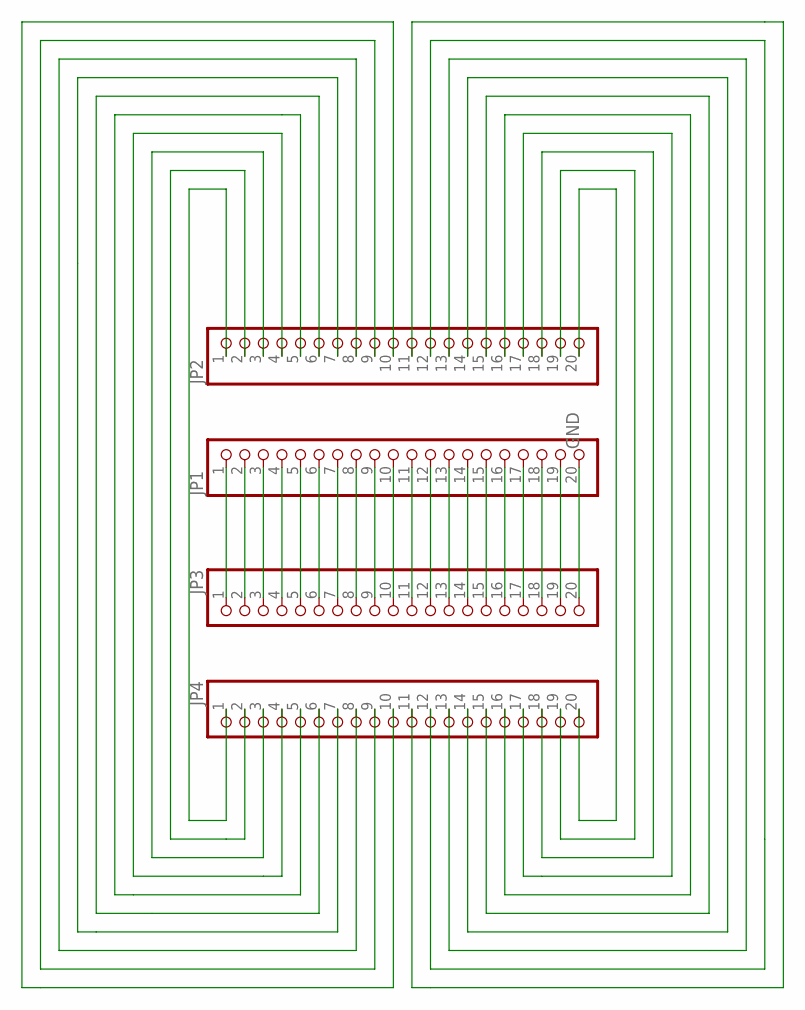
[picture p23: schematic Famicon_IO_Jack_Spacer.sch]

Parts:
JP1, JP2, JP3, JP4: PINHD-1X20_2.54-S; 1X20-S

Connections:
GND: JP1.20, JP3.20
unnamed: JP1.1, JP3.1
unnamed: JP1.2, JP3.2
unnamed: JP1.3, JP3.3
unnamed: JP1.4, JP3.4
unnamed: JP1.5, JP3.5
unnamed: JP1.6, JP3.6
unnamed: JP1.7, JP3.7
unnamed: JP1.8, JP3.8
unnamed: JP1.9, JP3.9
unnamed: JP1.10, JP3.10
unnamed: JP1.11, JP3.11
unnamed: JP1.12, JP3.12
unnamed: JP1.13, JP3.13
unnamed: JP1.14, JP3.14
unnamed: JP1.15, JP3.15
unnamed: JP1.16, JP3.16
unnamed: JP1.17, JP3.17
unnamed: JP1.18, JP3.18
unnamed: JP1.19, JP3.19
unnamed: JP2.20, JP4.20
unnamed: JP2.19, JP4.19
unnamed: JP2.18, JP4.18
unnamed: JP2.17, JP4.17
unnamed: JP2.16, JP4.16
unnamed: JP2.15, JP4.15
unnamed: JP2.1, JP4.1
unnamed: JP2.2, JP4.2
unnamed: JP2.3, JP4.3
unnamed: JP2.4, JP4.4
unnamed: JP2.5, JP4.5
unnamed: JP2.6, JP4.6
unnamed: JP2.14, JP4.14
unnamed: JP2.7, JP4.7
unnamed: JP2.13, JP4.13
unnamed: JP2.12, JP4.12
unnamed: JP2.8, JP4.8
unnamed: JP2.9, JP4.9
unnamed: JP2.11, JP4.11
unnamed: JP2.10, JP4.10

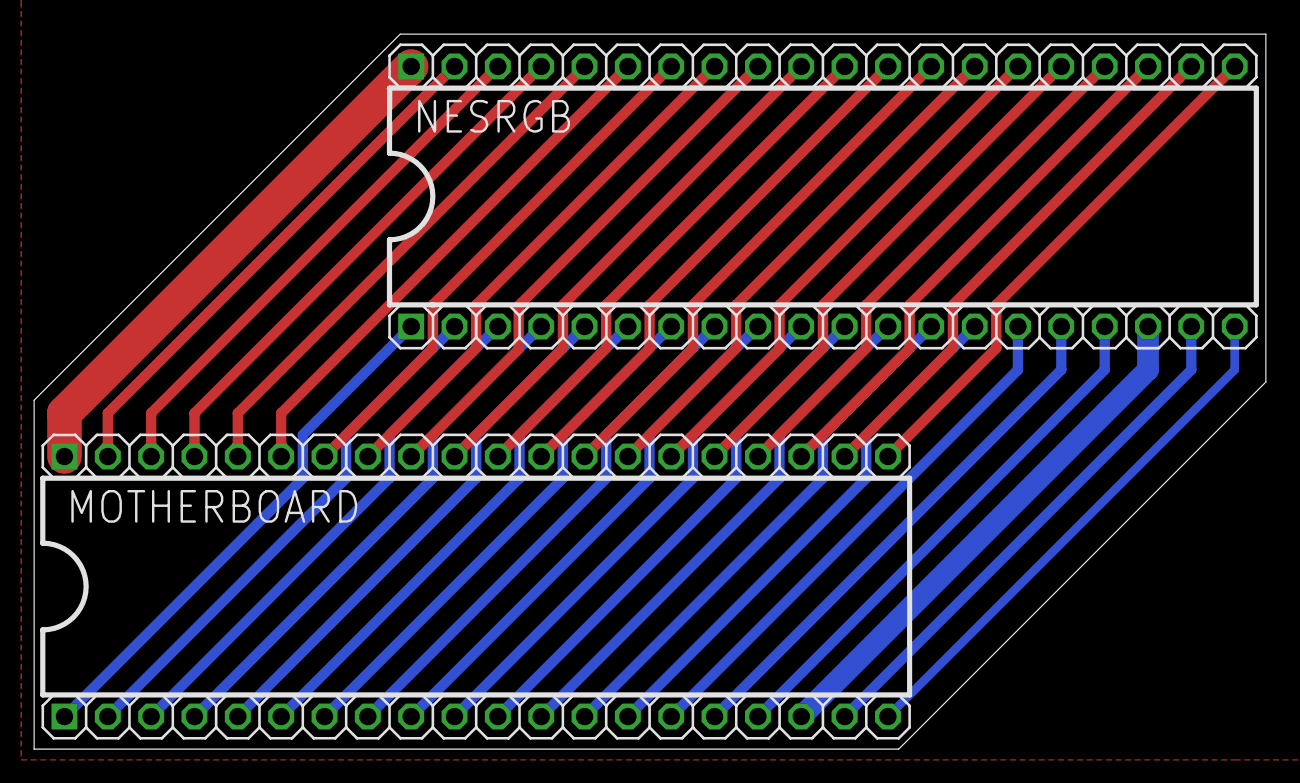
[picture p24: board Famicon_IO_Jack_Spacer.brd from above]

Board: 2 copper layers, 72.2 x 41.9 mm, 4 parts (0 on the bottom side), 40 nets.

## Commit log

2020-12-23 Create Borti_NESIO_1-5_NOCUT_BOM.xlsx
    Add BOM file for the NoCut.
    The MultiOUT is the same but ignore both miniDINs
    [Borti_NESIO_1-5_NOCUT_BOM.xlsx]
2021-02-18 Add Eagle files
    Add Eagle files
    [! NES_IO_US_NOCUT_REV1.5.brd, ! NES_IO_US_NOCUT_REV1.5.sch, ! NES_IO_US_SNES_REV1.5.brd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]
2021-04-28 Famicom I/O
    - Push Famicom I/O
    - Cleaning, Sorting
    - Add audio Tianfeng audio module
    [! Famicom_IO_NOCUT_REV1.5.brd, ! Famicom_IO_NOCUT_REV1.5.sch, ! Famicom_IO_SNES_REV1.5.brd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]

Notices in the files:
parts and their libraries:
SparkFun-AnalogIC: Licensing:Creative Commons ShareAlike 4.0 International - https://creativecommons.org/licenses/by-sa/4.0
